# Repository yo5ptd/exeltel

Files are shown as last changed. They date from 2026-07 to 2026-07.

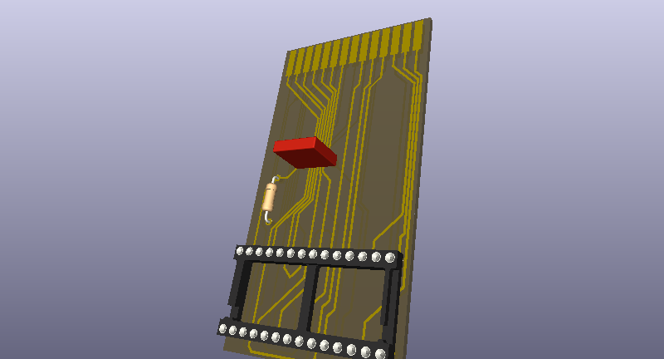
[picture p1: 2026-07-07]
exeltel.png

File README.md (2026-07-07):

# exeltel
exeltel cartridge for 27c256 eprom

## Introduction

exeltel exl 100, i had no basic catridge to test it, so i made one. 

## Hardware Documentation
Idea is to make it without vias, so i can use my CNC to mill PCB. I just added a pullup resistor and a cut jumper, so i can use 27c128 or 27c64 eproms too (not tested yet). Just make sure that when inserted, the eprom faces down (bottom of PCB marked with the letter B is facing up.

### Schematic and PCB Layout

[Schematic](sch.pdf)

[PCB Layout](pcb.pdf)

[Image](exeltel.png)

### Bill of Materials

Component Type | Reference | Description                             | Quantity | Possible Sources and Notes
-------------- | --------- | --------------------------------------- | -------- | --------------------------
PCB            |           | exeltel     	                           | 1        | mill it on your CNC
Capacitor      | C1        | 0.1 uF ceramic                          | 1        | regular ceramif filter cap
Resistor       | R1 	     | 10 k pullup                             | 1        | optional for  27c128 or 27c64

I was able to run exelbasic. I used ROM's from https://archive.org/details/Exelvision_EXL_100_TOSEC_2012_04_23

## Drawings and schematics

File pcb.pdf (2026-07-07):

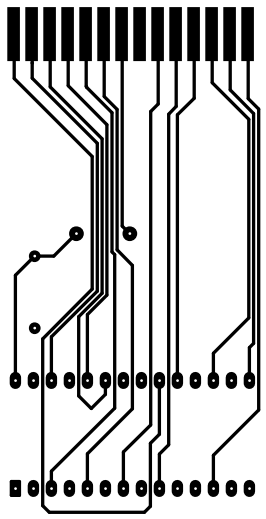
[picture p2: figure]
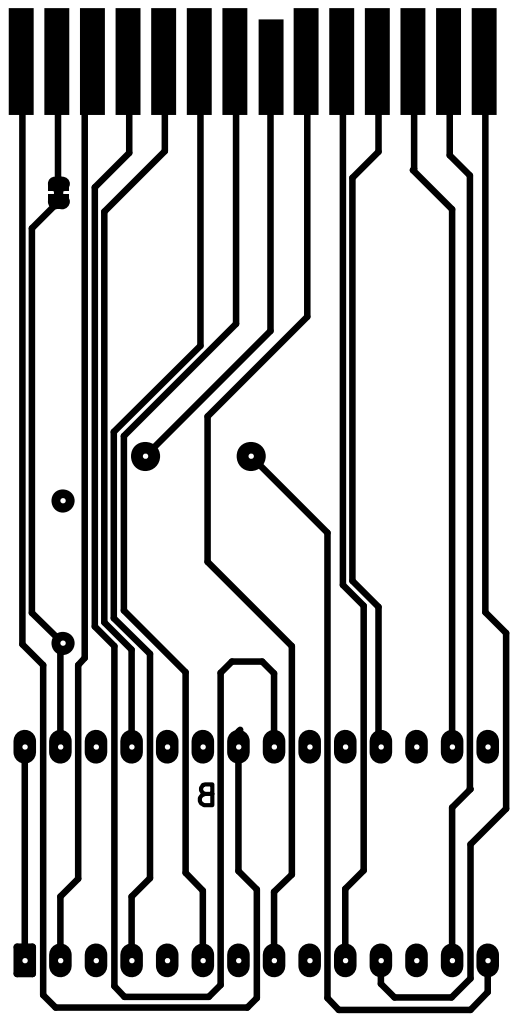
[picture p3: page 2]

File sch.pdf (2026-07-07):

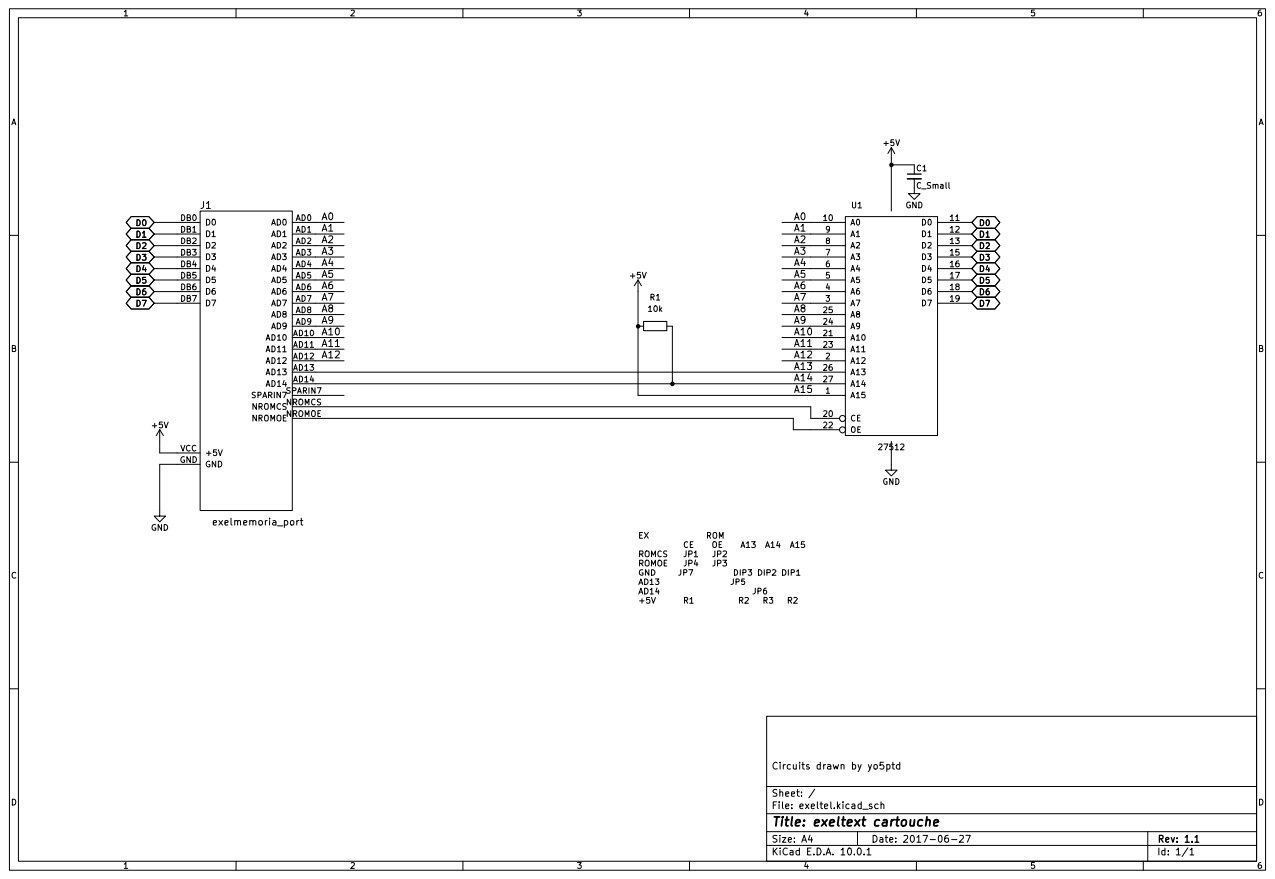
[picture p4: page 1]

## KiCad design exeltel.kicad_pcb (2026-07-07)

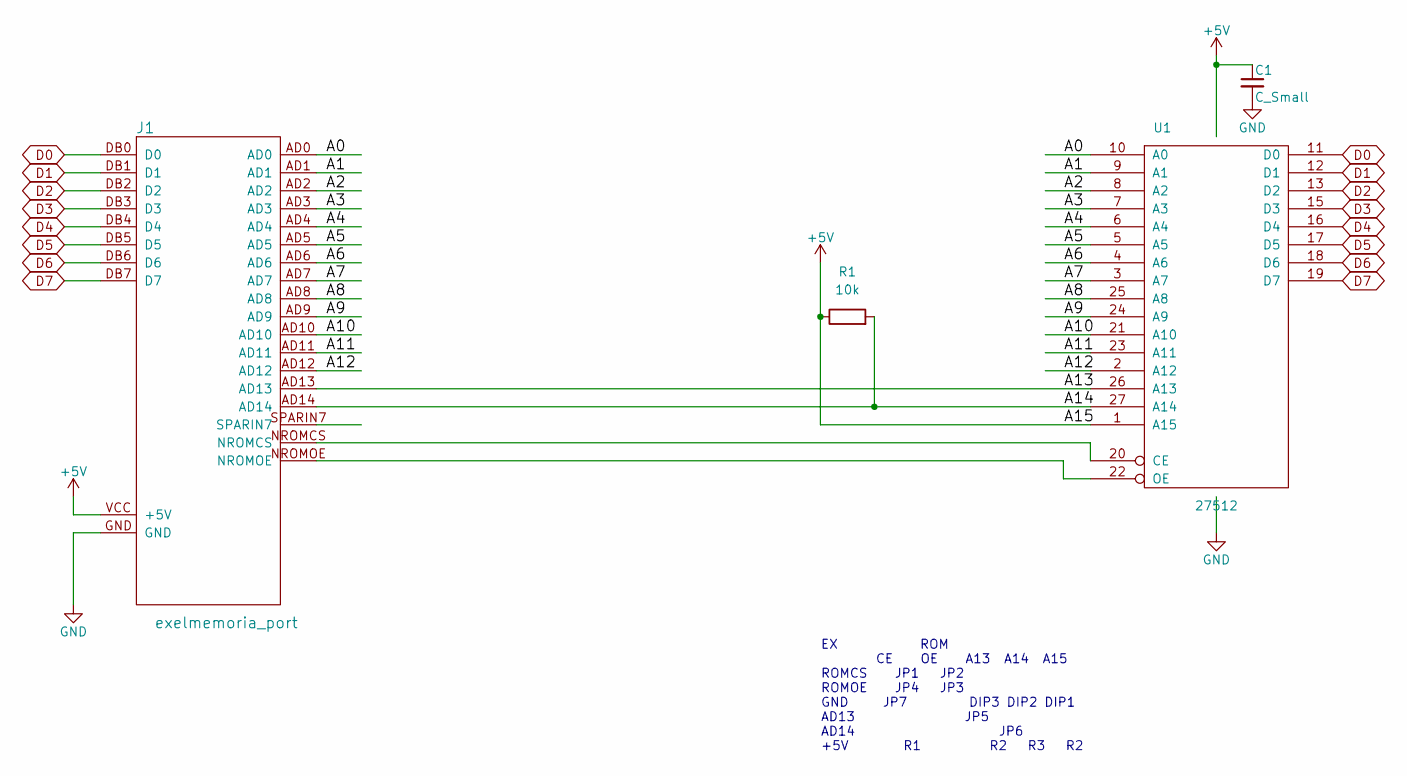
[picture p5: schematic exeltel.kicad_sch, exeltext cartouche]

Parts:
C1: C_Small; C_Rect_L10.0mm_W2.5mm_P7.50mm_MKS4
J1: exelmemoria_port; exeltel_edge
R1: 10k; R_Axial_DIN0207_L6.3mm_D2.5mm_P10.16mm_Horizontal
U1: 27512; DIP-28_W15.24mm_Socket_LongPads

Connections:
+5V: C1.1, J1.VCC (+5V), R1.1, U1.1 (A15), U1.28 (VCC)
/A0: J1.AD0, U1.10 (A0)
/A1: J1.AD1, U1.9 (A1)
/A2: J1.AD2, U1.8 (A2)
/A3: J1.AD3, U1.7 (A3)
/A4: J1.AD4, U1.6 (A4)
/A5: J1.AD5, U1.5 (A5)
/A6: J1.AD6, U1.4 (A6)
/A7: J1.AD7, U1.3 (A7)
/A8: J1.AD8, U1.25 (A8)
/A9: J1.AD9, U1.24 (A9)
/A10: J1.AD10, U1.21 (A10)
/A11: J1.AD11, U1.23 (A11)
/A12: J1.AD12, U1.2 (A12)
/A13: J1.AD13, U1.26 (A13)
/A14: J1.AD14, R1.2, U1.27 (A14)
D0: J1.DB0 (D0), U1.11 (D0)
D1: J1.DB1 (D1), U1.12 (D1)
D2: J1.DB2 (D2), U1.13 (D2)
D3: J1.DB3 (D3), U1.15 (D3)
D4: J1.DB4 (D4), U1.16 (D4)
D5: J1.DB5 (D5), U1.17 (D5)
D6: J1.DB6 (D6), U1.18 (D6)
D7: J1.DB7 (D7), U1.19 (D7)
GND: C1.2, J1.GND, U1.14 (GND)
unnamed: J1.NROMCS, U1.20 (CE)
unnamed: J1.NROMOE, U1.22 (OE)

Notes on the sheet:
EX ROM CE OE A13 A14 A15 ROMCS JP1 JP2 ROMOE JP4 JP3 GND JP7 DIP3 DIP2 DIP1 AD13 JP5 AD14 JP6 +5V R1 R2 R3 R2

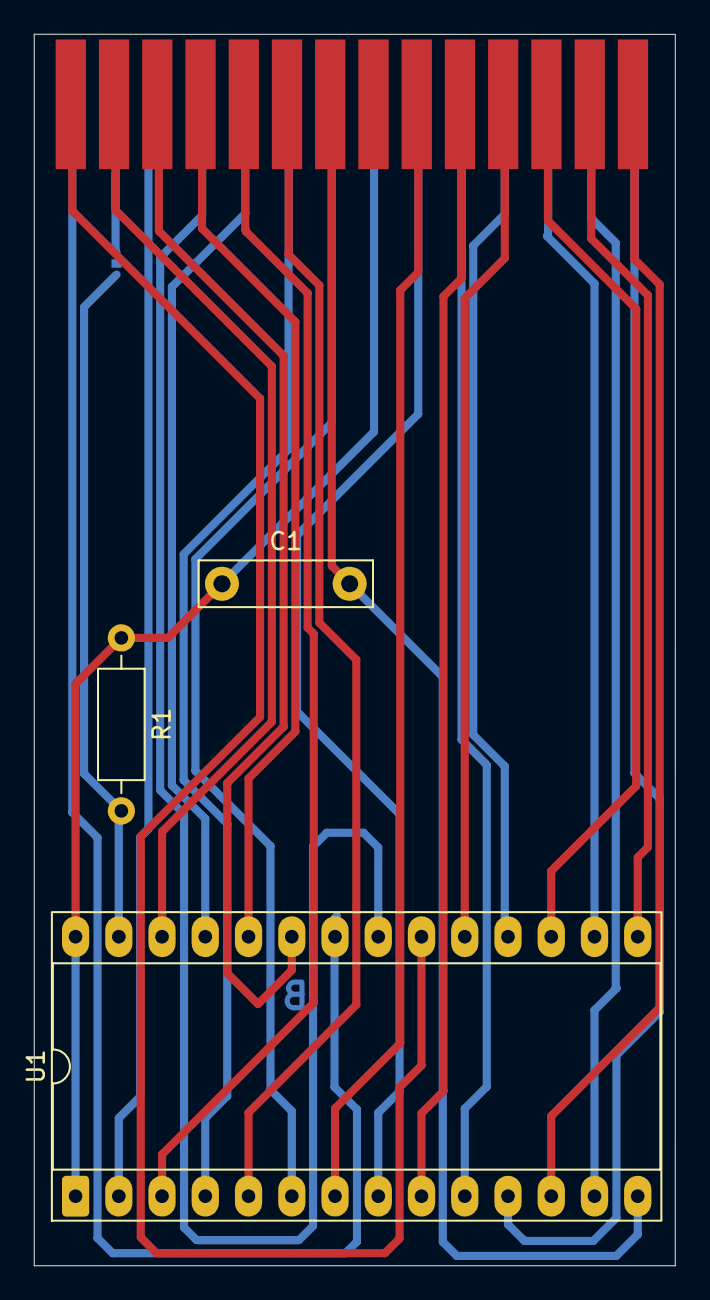
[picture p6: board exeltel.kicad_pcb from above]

Board: 2 copper layers, 37.7 x 72.3 mm, 4 parts (0 on the bottom side), 27 nets.

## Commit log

2026-07-07 Initial commit, ignoring local history
    [exeltel.kicad_pcb, exeltel.kicad_sch]
2026-07-07 Enhance README with exeltel cartridge details
    Added detailed documentation for the exeltel cartridge including introduction, hardware documentation, schematic, PCB layout, and bill of materials.
2026-07-07 Remove backups and lock files from tracking. Added gerbers.
